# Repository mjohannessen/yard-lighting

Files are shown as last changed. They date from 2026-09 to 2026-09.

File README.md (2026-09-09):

# yard-lighting

Distributed outdoor RGB LED garden lighting system. See [CLAUDE.md](CLAUDE.md) for the full architecture, hardware, and protocol spec.

## Wiring

Fixture heads use the fiber-optic flower-stem design in
[docs/fixture_construction_fiber.md](docs/fixture_construction_fiber.md) — a
buried base enclosure with a WS2815 node (used single-line, WS2811-style)
feeding a flexible fiber-optic + spring-wire stem up to a passive frosted
globe. The fiber's polished base end seats in direct contact against the
node's flat SMD face — no reflector cone, no air gap. There is no rigid pipe
riser and no electrical connection above the base enclosure.

### System overview

```
                     ┌──────────────────────┐
                     │  Mac Mini: openHAB   │
                     │ (schedules, scenes,  │
                     │  astro/weather rules)│
                     └──────────┬───────────┘
                                │ MQTT (LAN)
                                ▼
                     ┌──────────────────────┐
                     │  Hub Box             │
                     │  Pi Zero 2 W         │
                     │  Mosquitto broker +  │
                     │  MQTT↔serial bridge  │
                     └──────────┬───────────┘
                                │ USB (Hub+Ethernet HAT → powered USB hub)
          ┌─────────────┬─────────────┬─────────────┐
          ▼             ▼             ▼             ▼
     ┌─────────┐   ┌─────────┐   ┌─────────┐   ┌─────────┐
     │ Pico #1 │   │ Pico #2 │   │ Pico #3 │   │ Pico #4 │
     │ Zone 1  │   │ Zone 2  │   │ Zone 3  │   │ Zone 4  │
     └────┬────┘   └────┬────┘   └────┬────┘   └────┬────┘
          │ GP0         │ GP0         │ GP0         │ GP0
          ▼             ▼             ▼             ▼
     ┌───────────────────────────────────────────────────┐
     │       74AHCT125 — one chip, 4 channels             │
     │   (single quad level shifter; all 4 Picos share    │
     │            it, one channel per zone)                │
     └────┬────────────┬────────────┬────────────┬────────┘
          ▼             ▼             ▼             ▼
      300–470Ω      300–470Ω      300–470Ω      300–470Ω
      resistor on   resistor on   resistor on   resistor on
      zone 1 data   zone 2 data   zone 3 data   zone 4 data
      lead, at      lead, at      lead, at      lead, at
      chip output   chip output   chip output   chip output
          │             │             │             │
          ▼             ▼             ▼             ▼
      trunk cable,  trunk cable,  trunk cable,  trunk cable,
      zone 1        zone 2        zone 3        zone 4
      (12V·GND·Data, base enclosure to base enclosure)
          │             │             │             │
          ▼             ▼             ▼             ▼
      1st fixture,  1st fixture,  1st fixture,  1st fixture,
      zone 1:       zone 2:       zone 3:       zone 4:
      +100µF cap    +100µF cap    +100µF cap    +100µF cap
      across        across        across        across
      12V/GND at    12V/GND at    12V/GND at    12V/GND at
      node's leads  node's leads  node's leads  node's leads
```

### Per-fixture base enclosure wiring

Each fixture is a buried base enclosure (no rigid pipe riser) housing a
WS2815 node (LED holder insert, direct-contact fiber coupling) and the fixed
end of the fiber/spring-wire stem. The node's leads are permanently soldered
to two short pigtails at bench-assembly time, before the enclosure is ever
closed and sealed. Each pigtail exits through its own small sealed grommet
and ends in bare tinned lead wire — no connector is fitted at bench time.
Splicing to the trunk cable happens later, at install, **outside** the
enclosure, using gel-filled direct-bury connectors — a permanent splice, not
a field disconnect. A coiled service loop of extra trunk cable at each
fixture allows a future cut/re-splice without pulling new wire.

```
  trunk in ──────────┐                       ┌────────── trunk out
  (from prev fixture,│                       │           (to next fixture,
   or hub box)        │                       │            or none if last
  12V / GND / Data    │                       │            in zone)
                       ▼                       ▼           12V / GND / Data
         gel-filled direct-bury splices (outside enclosure)
      ┌─────────┐ ┌─────────┐ ┌──────────┐ ┌──────────┐
      │   12V   │ │   GND   │ │ data-in  │ │ data-out │
      │ 3-way tie│ │ 3-way tie│ │ 2-way    │ │ 2-way    │  NOT tied together
      └────┬────┘ └────┬────┘ └────┬─────┘ └────┬─────┘
           │           │           │            │
           │  (pigtail leads — bare wire, exit through sealed grommets)
           │           │           │            │
           ▼           ▼           ▼            ▲
        ┌───────────────────────────────────────────┐
        │     Base enclosure (sealed once, on the     │
        │             bench, at build time)            │
        │        ┌───────────────────────────┐        │
        │        │  WS2815 node (LED holder   │        │
        │        │  insert, direct-contact    │        │
        │        │  fiber coupling)           │        │
        │        └─────────────┬───────────────┘        │
        └──────────────────────┼───────────────────────┘
                                ▼
                    fiber → spring wire → globe
                    (flex zone: optics + mechanics only,
                     no electrical connection above this point)
```

Notes:
- Mark fixtures with one small hole on the DIN side, 2 holes indicate the first fixture in the node which has the capacitor between + and -
- **12V and GND** are a true common tie — one gel-filled connector each,
  with trunk-in, trunk-out, and the node's own pigtail lead all landed
  together.
- **Data is never a common tie.** The node fully decodes and regenerates the
  signal, so trunk-in-data→node-DI and node-DO→trunk-out-data are two
  separate gel-filled connectors. Tying all four data leads into one
  connector shorts the node's input and output together.
- The last fixture in a zone has no trunk-out — its connectors only carry
  trunk-in + node lead (or trunk-in + node-DI, with no downstream DO
  consumer).
- Data conductors must reach the node's own pads or a gel-filled connector
  only — never spliced mid-cable underground. See §5 of the fixture
  construction guide for the full convention.

### Wire/conductor legend

| Signal | Splice rule |
|---|---|
| 12V | Common-tie gel-filled direct-bury connector, outside the base enclosure |
| GND | Common-tie gel-filled direct-bury connector, outside the base enclosure |
| Data | Two separate gel-filled connectors (in→DI, DO→out) — never a common tie, never mid-cable |

## 3D-printed parts

The globe cradle and base enclosure are designed in FreeCAD; part specs,
dimensions, and construction steps are in [freecad.md](freecad.md).
Sources (`.FCStd`) and exported print files live in [freecad/](freecad/).

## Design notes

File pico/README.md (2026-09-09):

# Pico Firmware — MicroPython Setup & Bench Test

Covers flashing MicroPython onto a Pico and running the bench-test script
(`test_bench.py`) to validate the Pico → 74AHCT125 → LED signal path before
any serial/MQTT protocol exists. See [docs/wiring.md](../docs/wiring.md) for
the bench-test-stage vs. field-deployment wiring context.

## 0. Identify the board before flashing

- Pi zero is at 192.168.1.120

CLAUDE.md specifies RP2350 Pico 2 (standard, not Pico 2 W) as the architecture
constraint, but **confirm the actual chip on each board** before flashing —
don't assume, since earlier boards bought before the fleet standardized may
still be RP2040. Put the Pico in BOOTSEL mode (see step 2) and check:

```bash
dmesg | tail -20
```

Look at the `Product:` string:
- `Pico Boot` → RP2040 → use the `RPI_PICO` firmware
- `RP2350 Boot` → RP2350 (Pico 2 generation) → use the `RPI_PICO2` firmware

Flashing the wrong family's `.uf2` doesn't brick the board, but the
bootloader silently rejects the mismatched image — the board just stays in
BOOTSEL mode with no error and no `/dev/ttyACM0` ever appears, which looks
identical to a stuck/failed flash.

## 1. Install mpremote (on the Pi)

Raspberry Pi OS Bookworm blocks bare `pip install` outside a venv (PEP 668),
so use `pipx`:

```bash
sudo apt update && sudo apt install -y pipx
pipx install mpremote
pipx ensurepath
# reopen the shell (or `source ~/.bashrc`) so mpremote is on PATH
mpremote --version
```

If `pipx` isn't available, fall back to:
```bash
sudo apt install -y python3-pip
python3 -m pip install --user --break-system-packages mpremote
```

## 2. Flash MicroPython

1. Unplug the Pico's USB cable.
2. **Press and hold BOOTSEL**, plug the cable back in while still holding
   it, wait ~2 seconds, then release. It enumerates as a USB mass-storage
   drive instead of a serial port.
3. Confirm with `lsblk` — a new small (~128MB) disk appears (e.g. `sda1`).
4. Download the firmware matching the chip identified in step 0 (check
   https://micropython.org/download/ for the current release if these exact
   URLs have moved on):
   ```bash
   # RP2040 ("Pico Boot"):
   wget https://micropython.org/resources/firmware/RPI_PICO-20260406-v1.28.0.uf2 -O ~/micropython-pico.uf2

   # RP2350 ("RP2350 Boot", Pico 2 generation):
   wget https://micropython.org/resources/firmware/RPI_PICO2-20260406-v1.28.0.uf2 -O ~/micropython-pico2.uf2
   ```
5. Mount and copy:
   ```bash
   sudo mkdir -p /mnt/pico
   sudo mount /dev/sda1 /mnt/pico   # adjust device name per lsblk
   sudo cp ~/micropython-pico2.uf2 /mnt/pico/   # or micropython-pico.uf2 for RP2040
   sync
   ```
   The Pico reboots on its own once the copy finishes and the mass-storage
   drive disappears — that's normal, not an error.
6. Confirm it's back as a serial device:
   ```bash
   ls /dev/ttyACM*
   ```

## 3. Deploy and run the bench test

```bash
cd ~/Documents/yard-lighting
git pull
mpremote connect /dev/ttyACM0 cp pico/test_bench.py :main.py
mpremote connect /dev/ttyACM0 repl
[enter]
[>>>]
CTRL-D
[enter number of leds]

```

Copying to `:main.py` makes it run on every boot/reset — but copying alone
doesn't trigger that reset, so after `repl` connects you'll just see a
blank prompt. Press **Ctrl-D** to soft-reset the board; that runs
`main.py`, which immediately prints:

```
Number of LEDs:
```

Type the count of NeoPixels currently wired on GP0 (e.g. `1` when
isolating a single fixture on the test jig) and press Enter. It then
drives a rotating rainbow across all of them — each LED position gets a
distinct hue, and the pattern shifts continuously — to confirm the signal
path end to end. With a single LED it just sweeps that one fixture through
the full color wheel.

To disconnect the REPL without resetting the board, press **Ctrl-]**. To
re-run with a different LED count, reconnect (`mpremote connect
/dev/ttyACM0 repl`) and press Ctrl-D again.

## 4. 74AHCT125 wiring (bench test / single zone)

The 74AHCT125 is a quad buffer — 4 independent channels, each with an input
(`nA`), output (`nY`), and an **active-low** output-enable (`nOE`). CLAUDE.md's
build uses a single chip, all 4 channels, one per zone (the project is capped
at 4 zones); for a single-zone bench test, channel 1 is enough.

DIP-14 SN74AHCT125N pinout, channel 1:

| Signal | Pin | Connects to |
|---|---|---|
| 1A (input) | 2 | Pico GP0 |
| 1Y (output) | 3 | → 300–470Ω resistor → LED strip DIN |
| 1OE (output enable, active-low) | 1 | Tie to GND |
| VCC | 14 | 5V rail |
| GND | 7 | Common ground (Pico GND + LED GND) |

**1OE must be tied to GND**, not left floating — floating output-enable is
undefined logic and can leave the channel not driving at all, which looks
identical to a GP0-not-connected fault (LEDs just stay dark with no error
anywhere).

For additional zones on the same chip, repeat with channel 2 (2A=pin5,
2Y=pin6, 2OE=pin4), channel 3 (3A=pin9, 3Y=pin8, 3OE=pin10), and channel 4
(4A=pin12, 4Y=pin11, 4OE=pin13) — VCC/GND (pins 14/7) are shared across all
four channels on the chip.

## Troubleshooting

- **`mpremote ... TransportError: could not enter raw repl`** — the board
  isn't running MicroPython. Either it still has different firmware from a
  previous project, or the last flash was the wrong chip family (see step
  0). Re-flash with the correct `.uf2`.
- **BOOTSEL drive never appears in `lsblk`** — BOOTSEL timing is finicky
  through a hub. Fully unplug, hold the button *before* plugging back in,
  hold for ~2s after, then release.
- **Script runs but LEDs stay dark** — check GP0 → 74AHCT125 pin 2, and
  confirm pin 1 (1OE) is tied to GND, not floating.
- **LED shows a wrong color instead of the one commanded** (e.g. solid
  white comes out green or blue, and it's a *different* wrong color on a
  different run of the same script) — check that the LED's power supply
  ground and the Pico/74AHCT125 ground are actually tied together, not
  just both eventually routed to the same fixture. Without a common
  ground the node has no shared reference for the data signal's high/low
  thresholds, so it latches whatever crosses threshold rather than the
  intended value — confirmed root cause on the bench jig, see
  [docs/fixture_test_jig.md](../docs/fixture_test_jig.md).

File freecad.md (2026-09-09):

# Globe Cradle

A 3D-printable spherical cradle mount designed to hold a 59mm diameter globe,
with a bottom nipple to accept a 1/4" ID / 3/8" OD tube (interference/pressure
fit, no adhesive — see Assembly below; confirmed with the user 2026-07-29,
superseding the glued fit this part originally shipped with).

## Part Specifications

| Feature | Dimension |
|---|---|
| Globe diameter | 59mm |
| Inner radius (cup) | 29.5mm |
| Outer radius (cup) | 32mm |
| Wall thickness | 2.5mm |
| Cradle depth | ~7.4mm (1/8 globe) |
| Nipple outer radius  | 7.36mm |
| Nipple bore radius | 4.5mm (interference fit — was 4.86mm slip-fit-for-glue) |
| Nipple length | 20mm |
| Bore depth | 15mm |
| Tube OD (press fit)  | 9.525mm (3/8") |
| Tube ID | 6.35mm (1/4") |

## Files

- `models/light-cradle-top-refined.3mf` — current printable export (FreeCAD-generated mesh); this is the file actually in the repo and the one that's been printed and fit-tested
- No `.FCStd` source is currently checked into this repo — if it lives only in a local FreeCAD session or another location, add it here so the mesh isn't the only copy

## Suppliers

- Globe: https://www.superiorlighting.com/6-inch-plastic-globe-plain-lip-opening-white-opal-acrylic/

## As-built vs. this doc (2026-09-02)

Measured directly from `models/light-cradle-top-refined.3mf`'s mesh (2051 vertices /
4102 triangles), since no `.FCStd` source is in-repo to check against:

- **Globe stays 59mm** — confirmed with the user 2026-09-02, not changing.
- **Cup/rim diameter checks out.** The spec table's "outer radius (cup) 32mm" is the
  *sphere primitive's* radius used in the boolean construction (Construction Method
  step 1), not the finished rim's opening size — those are different numbers by
  design, and the table didn't distinguish them. For a 1/8-height cap of a 59mm
  globe, the rim opening's actual radius works out to ≈19.5mm (`sqrt(R² - (R-h)²)`
  with R=29.5mm, h=7.4mm), i.e. ≈39mm diameter — and the mesh measures a 40mm
  overall diameter at that rim. These agree; no design change here, just a doc
  ambiguity worth this note so it doesn't get mis-read as a mismatch again.
- **Nipple bore does not match this doc's spec, and this one is unresolved.** The
  doc specifies a 4.5mm bore radius (9mm diameter) sized for an interference press-fit
  against the 9.525mm-OD tube (see the Nipple bore radius row and the note below the
  spec table). The mesh's nipple, however, has a ~2.8mm-diameter (r≈1.4mm) center
  bore through most of its ~19mm length — sized like the *fiber-only* hole from the
  LED holder insert in
  [docs/fixture_construction_fiber.md](docs/fixture_construction_fiber.md) §1, not a
  tube-interference bore. The nipple's outer shaft also reads ~9.6mm OD (close to the
  tube's own 9.525mm OD), with a wider collar near the cup and a small flange at the
  tip. A triangle mesh doesn't preserve feature intent, so this could be: (a) the tube
  design changed to slide over the nipple rather than press into a bore, with the fiber
  routed through a separate small channel, or (b) this file is genuinely a different
  part (closer to the LED holder insert) that inherited the "cradle" name. Since the
  user has printed and fit-confirmed the current cradles, whichever it is clearly
  works — but the written spec below (Nipple bore radius, and the interference-fit
  note) is stale relative to the actual file and should be corrected once the intent
  is confirmed against the `.FCStd` source rather than the exported mesh.

## Construction Method

Built in FreeCAD 1.1.1 using the Part workbench:

1. Outer sphere primitive (32mm radius, full sphere)
2. Inner sphere primitive (29.5mm radius, full sphere)
3. Boolean Cut: outer minus inner → hollow shell
4. Box primitive (100x100x100mm) positioned to crop upper portion
5. Boolean Cut: shell minus box → cradle cup shape
6. Cylinder primitive for nipple outer wall (7.36mm radius, 20mm height)
7. Boolean Union: cup + nipple cylinder
8. Cylinder primitive for bore (4.5mm radius, 15mm height)
9. Boolean Cut: assembly minus bore cylinder → finished part

Bore radius revised from an earlier 4.86mm (a slip fit sized for adhesive)
down to 4.5mm — roughly 0.5mm diametral interference against the 9.525mm
tube OD, confirmed with the user 2026-07-29 in favor of a pressure-only
push-fit (no epoxy/PVC cement) per the Assembly section below. This
joint doesn't need to be watertight — nothing above the base enclosure is
electrical — it only needs to hold mechanically under the globe's weight
and wind-driven stem flex. FDM prints commonly come out slightly
undersized on holes, so test-fit the bore on the PLA prototype first and
adjust the radius before committing to an ASA production run.

## 3D Printing Notes

- Recommended material: PETG or PLA
- Layer height: 0.2mm - cups use 0.12mm reduce outer wall speed to 30-40mm/s
- Infill: 40%+ for strength around nipple
- Print orientation: cup opening facing up

## Assembly

1. Assemble base/led mount
2. Connect incoming/outgoing 12v/ground/data to led leads
3. Tubing/wire retainer are the same length, fiber is 50mm longer than tubing
4. Insert tubing through lid via compression seal and insert into nipple (pressure only)
5. Thread fiber through top of globe cup
6. Thread retaining wire into tube until flush with tube.
7. Adjust fiber so it seats into the led housing hole
8. Attach globe cup to tubing (pressure only)
9. Attach globe to holder

## Disassembly

1. Open base and disconnect incoming/outgoing wires
2. Remove globe from globe cup
3. Remove globe cup from tube
4. Remove fiber/wire from tubing
5. Remove tube from led retainer
6. Remove led retainer from base

## Base Housing

Weatherproof lower enclosure that sits at (not below) grade, holding the
30mm x 30mm x 10mm LED/fiber-alignment mount and the base of the stem.
Pinned to the ground with common drip-irrigation metal loop stakes rather
than buried, since burial was moved to the trunk cable only — the housing
itself stays at the surface, exposed to sprinklers and rain but not
flooding, and must be watertight since it contains the LED.

Design decisions locked in for this part, confirmed with the user
2026-07-29:
- **One-piece, sealant-sealed shell, but sealed once on the bench, not in
  the field.** The node's 4 leads (12V, GND, DIN, DOUT) are permanently
  soldered inside the housing to two short pigtails *before* the housing is
  closed and sealed — this whole assembly happens at build time, not at
  install time. Each pigtail ends in bare tinned lead wire, not a
  connector — the connection to the trunk cable is made later, at install,
  outside the housing (see connector decision below). Superseded 2026-08-27:
  the box is no longer field-swappable as a sealed unit; "failure" now means
  cutting the splices open and re-splicing, not unplug-and-swap. See the
  trade-off note there.
- **Cylindrical puck** shape — simplest Part-workbench boolean sequence
  (concentric cylinders), no corners to catch a mower/trimmer at grade.
- **Gel-filled direct-bury splice connectors at each of the two cable
  penetrations, spliced *outside* the housing, not through a bulkhead
  cutout.** Superseded 2026-08-27 — this section originally specified
  Deutsch DT-series quick-disconnect connectors (DT04-3P plug / DT06-3S
  socket) for field-swappability without cutting/resplicing wire; that
  decision was reversed in favor of lower cost and no dedicated crimp tool,
  accepting slower field service in exchange (rare fixture failures don't
  justify the added connector/tooling cost). Each pigtail exits the housing
  through a small sealed grommet bore and ends in bare wire a short distance
  outside the shell. The buried trunk cable's in/out ends are joined to the
  pigtails there with gel-filled direct-bury connectors (ZONE INDUSTRY CORP
  silicone-filled, UL 486G — see
  [docs/fixture_construction_fiber.md](docs/fixture_construction_fiber.md)
  §2 BOM), twist-on, no tool required. A coiled service loop of extra trunk
  cable at each box allows a future cut/re-splice without pulling new wire.
  Servicing a fixture = dig down to the box, cut all splices open, lift the
  box, splice in a replacement box's pigtails using the service loop's
  slack, rebury. This still eliminates the lever-nut-inside-the-box splice
  cavity from the earliest design — the splice just moved outside the box
  and changed connector technology twice since — see
  [docs/fixture_construction_fiber.md](docs/fixture_construction_fiber.md)
  §5 for the full wiring convention and BOM.
- **Stem port keeps the mount's stem boss fully inside the housing.** The
  mount's stem-side boss is 15mm dia x 10mm tall; the silicone tube itself
  is 9.525mm OD. Rather than letting the 15mm boss poke through the housing
  top (which would need an ~16mm port and leave the boss exposed to
  weather), the housing top port is sized to the **tube**, just above where
  it seats on the boss. This keeps the boss-to-tube joint fully enclosed and
  protected, and only the plain tube crosses the watertight boundary. If
  bench-fit shows the tube needs to seat *above* the housing top instead
  (e.g. the boss has to sit proud for stem geometry reasons), widen the
  port and revisit — flagged here so the trade-off isn't silently
  re-decided later.
- **Stem port seals with a compression grommet, not a sealant bead directly
  on the tube.** Confirmed with the user 2026-07-29: cured silicone sealant
  doesn't reliably bond to the tube's own cured-silicone surface (both are
  chemically the same inert, low-surface-energy material, so a sealant bead
  applied there mostly sits on top rather than adhering — a real risk at a
  joint that flexes every time the stem moves in the wind). Instead, the
  port holds a small rubber compression grommet (same category part as the
  IP68 cable glands used elsewhere in this project) sized to the tube's
  9.525mm OD, sealing by mechanical squeeze rather than adhesion. Sealant
  is still used, but only as a secondary bead around the grommet's own
  flange-to-cap joint — rigid printed plastic to rigid grommet body, which
  sealant bonds to fine, unlike the tube itself.

### Part Specifications

| Feature | Dimension | Notes |
|---|---|---|
| Overall shape | Cylindrical puck | Sits flush at grade |
| Outer diameter | 70mm | Shrunk from an earlier lever-nut-based draft (95mm) now that the node wires straight to pigtails with no in-box splice hardware — encloses the 30x30mm mount + pigtail dressing with margin |
| Overall height | 40mm | 30mm cup + 10mm cap, before final trim |
| Wall thickness | 3mm | Thicker than the globe cradle's 2.5mm — this part carries stake-down load at the flanges |
| Mount cavity (on internal boss)| 34mm x 34mm x 12mm | 2mm clearance around the 30x30x10mm mount block on each side and above |
| Stem port (in cap) | ~4mm tall collar, counterbored for a compression grommet | Grommet ID matches 9.525mm tube OD, seals by mechanical squeeze; grommet OD/flange size is [TBD] — confirm against the actual grommet product before finalizing the counterbore |
| Pigtail exit bores (in floor)  | 2x ~8mm bore, small grommet/potted seal | Trunk-in-side, trunk-out-side pigtail; offset to the side of the mount boss. Not a full trunk-cable gland — the actual splice (gel-filled direct-bury connector) sits outside the housing |
| Stake-mount flanges | 2x, opposite sides, 18mm x 12mm, 4.5mm through-hole | Sized for typical drip-irrigation loop-stake wire (~3mm dia) |
| Cap-to-cup joint | 2mm deep overlapping lip | Sealant-bead seam, sealed once at bench-assembly time |

### suppliers
- underground wire: https://cheapsprinklers.com/products/18-3x250-wire-18-3-x-250ft

### Construction Method

Built in FreeCAD 1.1.1 using the Part workbench — two separate solids (cup
and cap), same boolean-first approach as the globe cradle:

**Cup (lower body):**
1. Outer cylinder, 35mm radius, 30mm height
2. Inner cylinder cut, 32mm radius, positioned to leave a 3mm floor →
   hollow cup
3. Box or cylinder **union** for the internal mount boss (raised platform
   inside the cup floor, ~5mm tall, footprint sized to the 34mm x 34mm
   mount cavity) — a boss, not a recess, so the LED sits above any water
   that reaches the true floor
4. Two cylinder cuts through the floor for the pigtail exit bores (~8mm),
   offset to the side of the mount boss
5. Two box **unions** for the stake-mount flanges at the outer rim (opposite
   sides), then two cylinder cuts through each flange for the stake
   through-holes

**Cap (lid):**
6. Outer cylinder matching the cup's outer lip diameter, ~10mm height
7. Inner cylinder cut sized to the cup's 2mm overlap lip → thin disc that
   seats over the cup
8. Cylinder **union** for the stem-port collar (~4mm tall boss centered over
   where the mount's stem boss will sit)
9. Cylinder cut through the collar for the stem port, sized to the chosen
   grommet's insertion OD
10. Shallow counterbore cut at the collar's top face, sized to the
    grommet's flange OD and thickness, so the grommet seats flush and can't
    push through under stem movement

### 3D Printing Notes

- Prototype in PLA on the Anycubic Kobra to fit-check the mount cavity,
  pigtail exit bores, and stake-flange spacing before committing to ASA,
  per the existing fixture fabrication workflow's two-material process
- Recommended production material: ASA (UV/thermal stability for a
  surface-sited, full-sun part) — not PLA, per established workflow
- Layer height: 0.2mm; reduce outer wall speed near the stem-port collar
  and stake-flange holes for cleaner small-feature detail
- Infill: 40%+, especially through the stake-flange bosses — these carry
  the pinning load from the ground stakes
- Print orientation: cup opening facing up; cap printed flat, port collar
  facing up

### Bench Assembly (done once per box, before install)

1. Fit-check the mount block and stem boss dry in the cup's mount boss and
   cap's stem port before any sealant goes on
2. Solder the node's 4 leads to two short pigtails (in-side: 12V, GND, DIN;
   out-side: 12V, GND, DOUT), heat-shrink each joint, tin the free end of
   each pigtail wire — these stay bare leads until spliced to the trunk
   cable at install, not terminated in a connector at bench time
3. Feed each pigtail through its floor exit bore, seat the mount block on
   the internal boss, feed the stem up through the cap's port and seat the
   compression grommet in its counterbore around the tube
4. Run a continuous bead of clear flexible outdoor sealant (GE Silicone II,
   Sikaflex, Loctite Marine — not epoxy, matching the globe-seam convention)
   around the cup-to-cap lip, the grommet's flange-to-cap joint, and each
   pigtail exit bore — the grommet itself, not sealant, is what seals
   against the tube
5. Seat the cap onto the cup, tool the sealant fillets so water sheets off
   each joint rather than pooling; let cure per datasheet
6. Bench-test the node before it ever goes in the ground

### Field Install / Service

1. Strip the buried trunk cable's in/out ends and splice each to the
   corresponding pigtail leads with gel-filled direct-bury connectors
   (ZONE INDUSTRY CORP, per BOM), outside the housing
2. Coil a service loop of extra trunk cable near the box before
   backfilling, so a future re-splice doesn't require pulling new wire
3. Pin the housing to grade with a loop stake through each of the two
   flange holes, prongs pushed fully into soil
4. Confirm level and flush-to-grade seating, then backfill up to (not over)
   the housing
5. **To service a failed fixture**: dig down to the box, cut all splices
   open, lift the box out, splice in a replacement box's pigtails using the
   service loop's slack, rebury

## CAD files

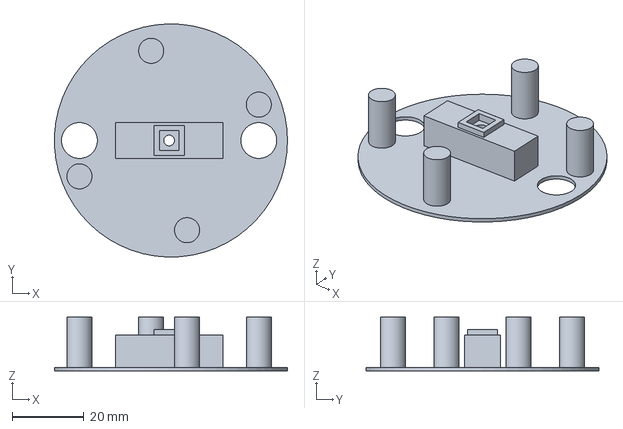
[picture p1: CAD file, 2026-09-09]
freecad/led-insert.FCStd
65.0 x 65.0 x 15.0 mm

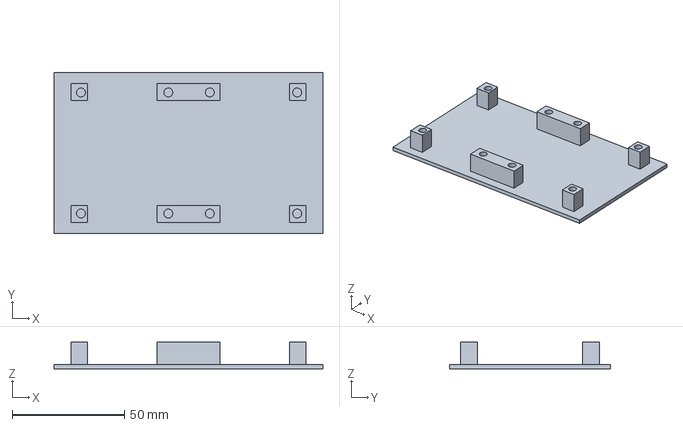
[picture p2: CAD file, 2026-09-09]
freecad/outdoor led final models/box-part-mounts-buck-plate.3mf
120.0 x 72.0 x 12.0 mm

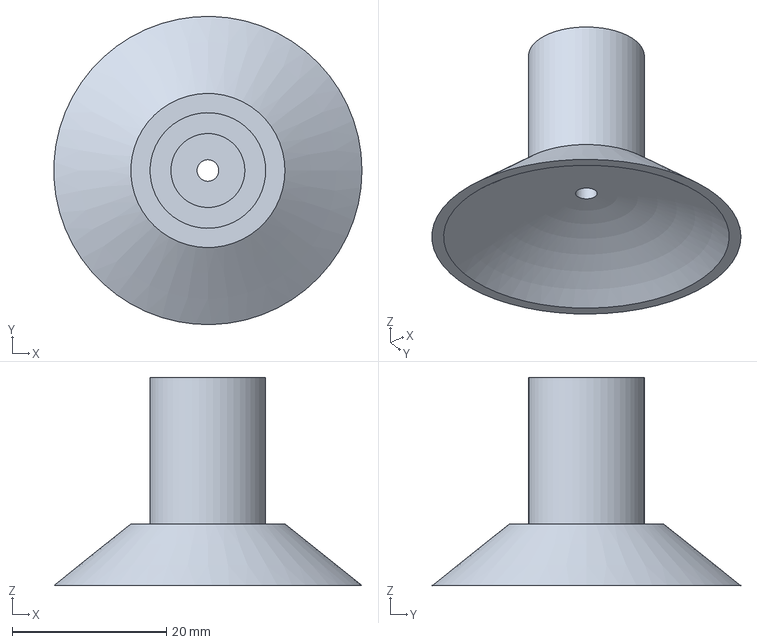
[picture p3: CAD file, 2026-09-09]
freecad/light-cradle.FCStd
40.0 x 40.0 x 27.0 mm

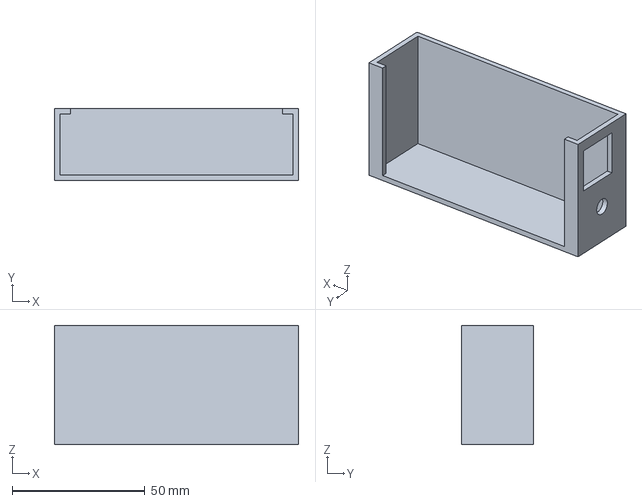
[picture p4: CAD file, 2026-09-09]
freecad/outdoor led final models/usbholder.3mf
92.0 x 27.0 x 45.0 mm

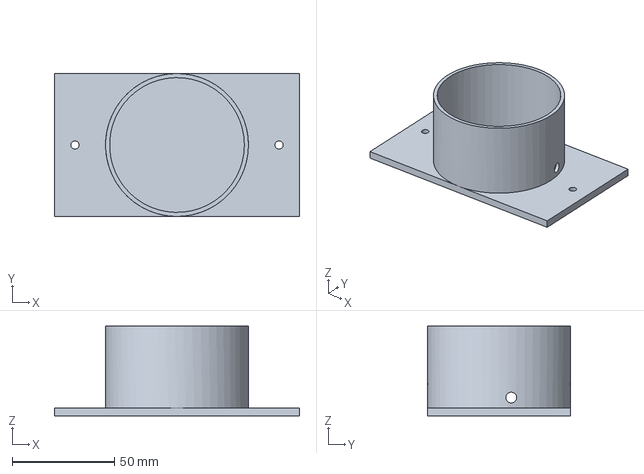
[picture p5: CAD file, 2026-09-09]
freecad/light-fixture-housing-base.FCStd
120.0 x 70.0 x 44.0 mm

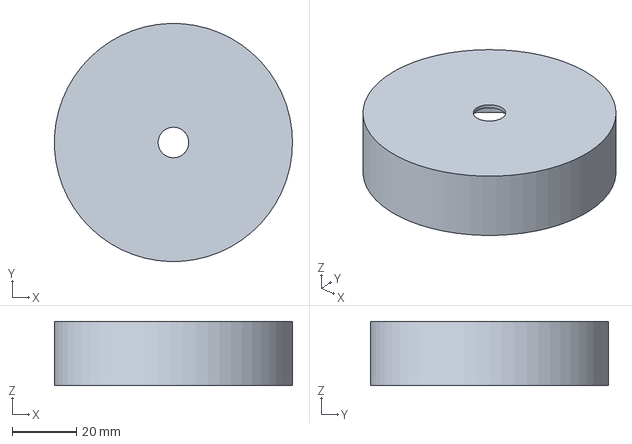
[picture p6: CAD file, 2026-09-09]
freecad/light-fixture-housing-cap.FCStd
73.9 x 74.0 x 20.0 mm

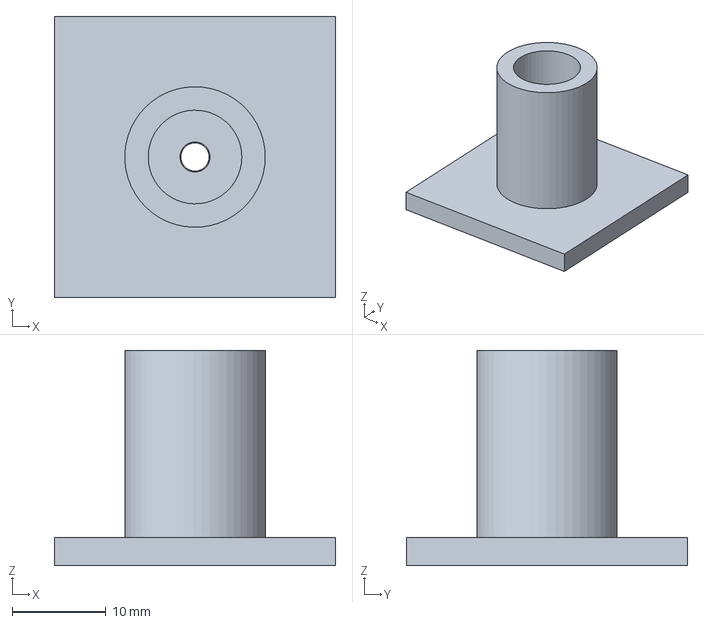
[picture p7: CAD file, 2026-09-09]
freecad/led-interior-mount-top.FCStd
30.0 x 30.0 x 23.0 mm

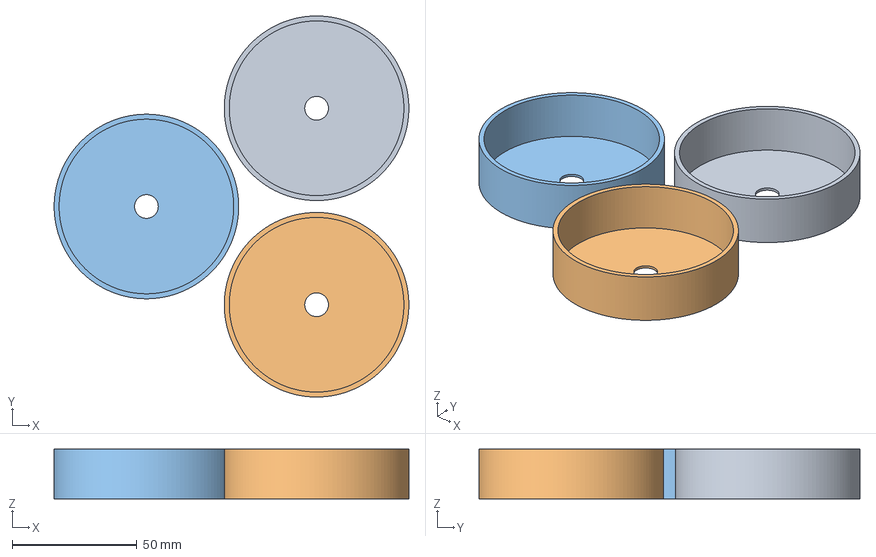
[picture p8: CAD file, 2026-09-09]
freecad/outdoor led final models/light-fixture-housing-cap.3mf
142.2 x 152.8 x 20.0 mm

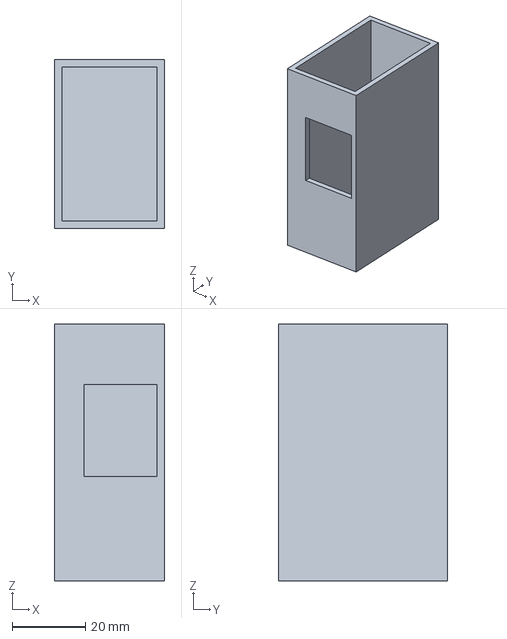
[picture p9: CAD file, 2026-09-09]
freecad/outdoor led final models/piholder.3mf
30.0 x 46.0 x 70.0 mm

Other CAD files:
freecad/outdoor led final models/led-insert.3mf
freecad/outdoor led final models/light-cradle-top-refined.3mf
freecad/outdoor led final models/led-interior-mount-top-Cut003.3mf
freecad/box-part-mounts.FCStd
freecad/outdoor led final models/light-fixture-housing-base.3mf

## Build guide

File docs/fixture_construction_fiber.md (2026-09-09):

# Fixture Construction Guide — Fiber-Optic Flower-Stem LED

1.  3d print parts:
    - base and cap = PETG
    - globe cup, led retainer and upper nipple all PLA
2.  Cut silicon tube to desired length
3.  Cut retaining wire (coat hanger wire) to the length of the silicon tube
4.  Cut the fiber 60mm longer than the silicon tube
5.  Cut diffuser rod to 10mm lengths
6.  Drill fiber hole in diffuser 1/2 of length
7.  Polish the fiber end touching the led — this end must stay clear and flat,
    the opposite treatment from the frosted globe-end tip in Step 6:
  - Score and snap, or cut square with a sharp blade/fiber-optic cutting tool,
   as close to perpendicular to the fiber axis as you can get by eye.
  - Wet-sand the end face flat against fine sandpaper on a hard, flat surface
   (a scrap of glass or tile works), fiber held perpendicular to the paper.
   Step through grits: ~400 → 600 → 1000 → 1500 → 2000, a few figure-eight
   strokes per grit, wiping the face clean between grits so a coarser
   scratch doesn't carry forward.
  - Finish with a metal-polish compound (e.g. Brasso) on a soft cloth or
   felt pad, or a plastic-polish compound (e.g. Novus 2/1), until the face
   looks clear rather than frosted — held up to light, you should see
   through it, not a matte scatter.
  - Inspect the finished face against a light source: it should be flat,
   perpendicular, and glassy-clear with no visible scratches, chips, or
   rounding at the edge before seating it against the LED.
8. Glue diffuser to unpolished end of fiber

# Final Assembly
1.  Cut 2 pigtails from the main cable 20cm each, Strip one end 70mm (inside), the other 30mm and strip ends
2.  Feed lond end of supply pigtail through the fixture and bend upwards
3.  Pull led wires and cable wires through the retainer holes
4.  Solder connections (VCC to led, in/out red, GND to led gnd-in-out-white, blue to DIN, DOUT to continued blue)
5.  For first fixture in node, add capacitor to VCC/GND (long wire is +)
6.  Trim cap and based for tight fit
7.  Check nipples for easy tube insertion.
8.  Add globe cap to tube, insert retaining wire and fiber.
9.  insert tube into base with about 10mm inside
10. Align fiber with led hole
11. Lower cap assembly into base
12. Attach globe

- Once assembled correctly seal all joints with silicon sealant

## Stem/globe sub-assembly (moved from docs/fixture_test_jig.md)

1.  Mark DIN on the fixture
2.  Insert the hose into the base cap and pull 1/2 way up hose
3.  Insert fiber into globe cap [glue here? - globe, cap and fiber all in place?]
4.  Insert hose into globe assembly
5.  Insert retaining wire into hose
6.  Push fiber into led holder until set
7.  Seat hose into base nipple
8.  Pull down cap to seat - adjust hose for fit
9.  Add globe to top (see 3)

## Component measurements

**Note:** these predate, and have not been reconciled with, the nipple
bore discrepancy already flagged in freecad.md (spec vs. as-printed mesh) —
treat both as unresolved until checked against current printed parts.

base nipple
  - total depth 35mm - 25mm for hose - additional 10mm for fiber to led hole
globe assembly
  - hose insert depth 10mm
  - from nipple entrance to top of diffuser - 60mm
    - hose insert - 10mm
    - fiber + diffuser - 50mm
    - inside cradle to diffuser top - 35

Example - for fiber 240mm
  - hose/wire 180

# Bill of materials

WS2815, 5050 SMD, DC12V, individually addressable | Cut singly from a [12V WS2815 strip, 60 LEDs/m](https://www.superlightingled.com/12v-ws2815-individually-addressable-5050-rgb-led-lights-strip-60ledsm-p-2133.html); 
Fiber optic cable -  PMMA (acrylic) end-glow fiber, ~3mm core 
Spring wire | 304 stainless steel, straight, full-hard temper, 1.4/1.6/1.8mm (bench-test set) or coathanger wire
Silicone tubing | Black silicone, 1/4"ID x 3/8"OD 
Diffuser bead  ~10–15mm frosted/opal acrylic bead  Epoxied to the fiber's globe-end tip 
Fine grit sandpaper
2.5" frosted acrylic ball
100% silicone sealant — GE Silicone II (or equivalent)
18 AWG 3 conductor underground wire

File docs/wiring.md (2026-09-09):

# Wiring — Bench Test Stage → Field Deployment

## Stage 1: Bench test (current)

Goal: validate the Pico → dispatch → LED signal path for two independent
zone branches before adding the field-scale power system (buck converters,
underground runs, WS2815 strings).

**Setup:** 2 Picos (one per branch), 24V bench PSU feeding both a 24V→5V
buck (Picos) and a 24V→12V buck (LED power), 1 real WS2815 node per Pico.
Each Pico's node will later gain a second WS2815 on the same branch (2
nodes per Pico) — not yet wired.

**Pins (same as field deployment, per Pico):**
| Pin | Function |
|---|---|
| GP0 | Data out → 74AHCT125 input |
| VBUS | 5V in |
| GND | Common ground |

**Still required at bench scale:**
- **24V→5V and 24V→12V buck converters** — both now in the loop, off the
  same 24V bench PSU, same as field deployment. No more standalone 5V
  supply standing in for them.
- **74AHCT125 level shifter**, one gate per Pico's GP0/data line (2 of the
  chip's 4 gates used; both Picos share the same physical chip). This isn't
  a 12V-vs-5V power concern — it's that the Pico's 3.3V logic sits below the
  ~5V (0.7×Vdd) data threshold NeoPixel-protocol pixels expect. A short
  bench wire may *appear* to work without it, but that's out of spec and
  won't validate the real signal path used in the field build.

**Not needed at this stage:**
- 300–470Ω data-line resistor / 100µF cap — cheap insurance if on hand;
  with only 1 WS2815 node per branch, inrush current on power-up is minimal
  (the cap's role in CLAUDE.md's *Known Constraints* is protecting the
  first node in a full field string, not a lone bench node), so not
  required yet.

**WS2815 BI/BO:** now real WS2815 nodes, so the backup-data pins physically
exist — leave them unwired at the bench too, matching the field convention
in CLAUDE.md (single-line, WS2811-style; BI/BO unused).

**Power draw:** trivial at 2 WS2815 nodes total even at full white
(~18mA/LED) — no special power sequencing needed on bench supply. Revisit
once each branch grows to 2 nodes.

## Stage 2: Field deployment (Phase 1 — 4 zones)

Real installation, replacing the bench's single 5V supply with the full 24V
power system and scaling from 2 bench branches to the 4 physical zones
leaving the hub box. One 24V/300W PSU feeds two independent buck converters
— nothing downstream shares a raw 24V rail.

```
24V/300W PSU
  │
  ├─► 24V→12V buck (5A) ──► common 12V/GND bus ──► 4× IP67/68 3-pin connector
  │                                                  └─► zone N trunk (12V + GND)
  │
  └─► 24V→5V buck (5A) ──► Pi Zero 2 W + USB Hub/Ethernet HAT
                              │
                              └─► powered USB hub ──► 4× Pico (VBUS 5V, GND, USB serial)
                                                         │
                                                         └─► GP0 ──► 74AHCT125 gate ──► 300–470Ω resistor ──► zone N trunk (Data)
```

**Power:**
- **24V→12V buck, 5A** — all 4 WS2815 strings share this converter's output
  at a common bus in the hub box; each zone taps it through its own IP67/68
  connector, not a shared underground run.
- **24V→5V buck, 5A** — feeds the Pi Zero 2 W (via the stacked USB Hub +
  Ethernet HAT, GPIO 5V) and, through that hub's USB-A port, the powered USB
  hub. Picos draw 5V over VBUS from the powered USB hub's ports — they are
  not wired to the buck converter directly.

**Signal — one 74AHCT125, 4 zones:**
- All 4 gates of a single quad 74AHCT125 are used, one per Pico: Pico GP0 →
  gate in, gate out → that zone's 300–470Ω resistor → underground data
  conductor. The four gates are electrically independent — no bussing
  between zones, same as the separate 12V/GND taps above.
- This is the full build: the project is capped at 4 zones permanently
  (hub box space constraints), so this single chip and the 4-port USB hub
  cover the whole system — no second 74AHCT125 or expansion is planned.

**USB (Pi ↔ Picos):**
- Pi Zero 2 W → USB Hub + Ethernet HAT (stacks on GPIO header, taps Pi's USB
  via pogo pins) → one USB-A port feeds the powered USB hub → 4 Picos.
- Each Pico enumerates as `/dev/ttyACMn` in connection order; assign stable
  `/dev/ttyPICOn` symlinks via udev (see CLAUDE.md *Deployment* section)
  before wiring `pi/config.py`'s zone→port map.

**Underground trunk, ×4 (one per zone):**
- 3-conductor: 12V, GND, Data. WS2815's BI/BO backup pair is intentionally
  left unwired (see CLAUDE.md *Architecture Constraints*).
- 100µF cap across 12V/GND at each zone's first base enclosure node leads —
  not optional, protects against power-on surge.
- Splices only at base enclosure gel-filled direct-bury connectors
  (ZONE INDUSTRY CORP silicone-filled, UL 486G, 20–8 AWG — see BOM), per
  CLAUDE.md §*Underground trunk cable*; no
  mid-cable splices. Each fixture gets a coiled service loop of extra
  trunk cable to allow a future cut/re-splice, since this is a permanent
  joint rather than a field disconnect.

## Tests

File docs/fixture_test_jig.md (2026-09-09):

# Fixture Test Jig — Pre-Burial Bench Test

A standalone test rig for lighting up one fixture's WS2815 node — via its
bare pigtail leads — before the base enclosure is glued shut and before the
pigtails get spliced to trunk cable. This is what satisfies the "Node
addresses and lights correctly on the bench" line in
[docs/fixture_construction_fiber.md](fixture_construction_fiber.md) §6's
pre-burial QC checklist, done right after Step 3 (pigtails soldered) or
Step 4 (base assembled) — whichever point the enclosure is still open enough
to reach the leads — and again at Step 9 after the globe is mounted.

This is a separate, permanent bench fixture, not a one-off wiring — build it
once and reuse it for every fixture.

## Components

| Part | Notes |
|---|---|
| Pico 2 (RP2350) | Same board as the field build (CLAUDE.md architecture constraint) — running MicroPython, per [pico/README.md](../pico/README.md) |
| 74AHCT125 quad level shifter | Only 1 of 4 channels used; same part as the field build and the bench-test rig ([pico/README.md](../pico/README.md) §4) |
| 300–470Ω resistor | Data line, between the 74AHCT125's output and the node's DI clip lead — matches the field convention (CLAUDE.md *Per zone* table) |
| 100µF capacitor | Across the 12V/GND clip leads, as close to the node as the clips allow — cheap insurance against power-on surge into a single node, same reasoning as CLAUDE.md's *Known Constraints* note (protects the node on connection, when clip contact bounce can spike current briefly) |
| 3× test clip leads (or fine hook probes) | 12V, GND, DI — clip directly to the fixture's bare pigtail leads. Use the **in-pigtail** (DI), never the out-pigtail (DO) — DO is the node's regenerated output toward the next fixture in the chain and carries no signal when nothing is driving it |
| Bench power supply, 12V | Fixture LED power only — set the voltage before connecting, don't rely on the jig to protect against an unset/wrong supply voltage |
| Raspberry Pi (test host) + USB cable | Host for flashing/running the Pico over `mpremote` (see Firmware below); also powers the Pico (VBUS) and, from the Pico's VBUS pin, the 74AHCT125's 5V VCC |
| Alligator clip → bare wire, or a small terminal block | At each of the 3 test leads' fixture end, sized for the pigtails' 26–30AWG silicone lead wire ([fixture_construction_fiber.md](fixture_construction_fiber.md) §2 BOM) |

Everything above except the clip leads and bench PSU is identical to the
existing bench-test 74AHCT125 setup in
[pico/README.md](../pico/README.md) §4 — build this jig on the same
protoboard/breadboard layout if one is already on hand from that setup.

## Wiring

```
Pico VBUS (pin 40)  ──► 5V rail
Pico GND  (pin 23)  ──► 5V rail GND / 74AHCT125 pin 1 (1OE) / pin 7 (GND)
Pico GP0  (pin 1)   ──► 74AHCT125 pin 2 (1A)
74AHCT125 pin 3 (1Y) ──► 300–470Ω resistor ──► DI clip lead
74AHCT125 pin 14 (VCC) ──► 5V rail

Bench 12V PSU (+) ──► 12V clip lead
Bench 12V PSU (–) ──► GND clip lead (common with Pico/74AHCT125 GND)
100µF cap ── across the 12V and GND clip leads, at the clip end
```

(74AHCT125 indentation notch is on the lower left; see
[pico/README.md](../pico/README.md) §4 for the full pinout table.)

Clip order onto the fixture's pigtail: **GND first, then 12V, then DI** —
same reasoning as any live power connection, minimizes the chance of the
data or 12V lead briefly floating against the wrong contact while clipping
on. Unclip in reverse order (DI, then 12V, then GND).

**The three grounds must be common**: bench PSU return, Pico GND, and
74AHCT125 GND all have to tie together, exactly like the field build's
single common ground (CLAUDE.md *Pico pin assignments*). If the bench PSU
and the USB power source are two separate physical supplies (likely, since
one is 12V and the other is 5V-over-USB), run a wire between their two
negative/ground points — don't assume they share a ground just because both
eventually reach the same fixture.

**Confirmed failure mode:** a missing/floating common ground here doesn't
just leave the node dark — it produces a *wrong but plausible-looking*
color (e.g. commanding solid white and getting solid green or blue
instead, differently on different runs of the same script), because the
node has no shared zero-volt reference to judge the incoming signal's
high/low thresholds against. Check continuity between the bench PSU's
negative terminal and the Pico's GND pin (should read ~0V) before
suspecting the resistor, cap, clips, or the node itself.

**1OE must be tied to GND**, not left floating — see
[pico/README.md](../pico/README.md) §4 for why a floating output-enable
looks identical to a disconnected data line (LEDs just stay dark).

## Firmware

With the Pico connected via USB to the Pi test host, flash
[pico/test_bench.py](../pico/test_bench.py) using `mpremote` from the Pi
per [pico/README.md](../pico/README.md) §§1–3, then follow that guide's
REPL steps and enter `1` at the **Number of LEDs** prompt when testing one
fixture on this jig (it also accepts the full daisy-chained count when
testing a multi-fixture run). It then drives a rotating rainbow across all
configured LEDs — each position gets a distinct, continuously shifting hue
— which is what §6's QC checklist checks color uniformity and hot-spot
issues against.

## Using the jig

1. Set the bench PSU to 12V, **outputs off**, before clipping on.
2. Clip GND, then 12V, then DI onto the fixture's in-pigtail bare leads
   (never the out-pigtail/DO).
3. Enable the bench PSU output.
4. From the Pi test host, confirm the Pico is running `test_bench.py` and
   showing the rainbow (see [pico/README.md](../pico/README.md) §3 for
   the `mpremote`/REPL steps).
5. At the globe, check per
   [fixture_construction_fiber.md](fixture_construction_fiber.md) §6: color
   uniformity through the rainbow, no hot-spot opposite the fiber tip,
   adequate brightness, and — if the stem is already built — that hand-flexing
   the stem doesn't disturb the light (a loose LED-to-fiber contact would
   show up as flicker here).
6. Disable the bench PSU output, then unclip DI, 12V, GND in that order.

If the node doesn't light: check the DI clip is actually on the
**in**-pigtail and not the out-pigtail (both leads look identical once bare
and tinned — mark them at Step 3 of
[fixture_construction_fiber.md](fixture_construction_fiber.md) if this is a
recurring mix-up), then work through
[pico/README.md](../pico/README.md)'s troubleshooting section — the failure
modes (floating 1OE, wrong GP0 wiring) are the same on this jig as on the
bench-test rig.

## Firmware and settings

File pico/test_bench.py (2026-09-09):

"""
Bench-test-stage hardware smoke test — see docs/wiring.md Stage 1.

Confirms the physical signal path (Pico GP0 -> 74AHCT125 -> NUM_LEDS x NeoPixel)
before any serial/MQTT protocol exists. Not part of the pico/main.py
dispatch loop.

Displays a rotating rainbow across all LEDs: each position gets a distinct
hue, and the whole pattern shifts over time. With NUM_LEDS=1 this sweeps
that single fixture through the full color wheel. Useful for confirming
per-position data integrity (each fixture should show a different, stable
color, not a corrupted one) and for exercising repeated np.write() calls
at a steady pace, unlike a single static write.

Prompts for the number of LEDs over the serial REPL on each run, so the
jig can be repointed at 1 node or the full daisy-chained count without
editing this file. Requires an attached REPL session (e.g. `mpremote
connect /dev/ttyACM0 repl`, press Ctrl-D to run) to answer the prompt.
"""
from machine import Pin
from neopixel import NeoPixel
import time

DATA_PIN = 0


def wheel(pos):
    """(r, g, b) for a position 0-255 on the color wheel."""
    pos = pos % 256
    if pos < 85:
        return (255 - pos * 3, pos * 3, 0)
    if pos < 170:
        pos -= 85
        return (0, 255 - pos * 3, pos * 3)
    pos -= 170
    return (pos * 3, 0, 255 - pos * 3)


while True:
    try:
        NUM_LEDS = int(input("Number of LEDs: "))
        if NUM_LEDS > 0:
            break
    except ValueError:
        pass
    print("Enter a positive integer.")

np = NeoPixel(Pin(DATA_PIN), NUM_LEDS)

offset = 0
while True:
    for i in range(NUM_LEDS):
        np[i] = wheel((i * 256 // NUM_LEDS) + offset)
    np.write()
    offset = (offset + 1) % 256
    time.sleep(0.05)

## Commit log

2026-07-20 Update hub box hardware to Ethernet HAT, add wiring and fixture construction docs
    CLAUDE.md/README: correct hub box networking from USB-OTG hub + USB-ethernet
    adapter to the Pi Zero USB Hub + Ethernet HAT actually in use. Rewrite
    README's wiring section to match the current fiber-optic flower-stem fixture
    design (WS2811 base enclosure, 3-conductor trunk, lever-nut splicing) instead
    of the retired rigid pipe-riser/WS2815-DOUT design.
    docs/wiring.md: bench-test-stage vs field-deployment wiring reference.
    docs/fixture_construction_fiber.md: full build guide for the fixture head.
2026-07-20 Update CLAUDE.md architecture spec to match fiber-stem fixture design
    Replace stale WS2815/4-wire/PCB-pin references with the WS2811 3-conductor
    trunk + base-enclosure lever-nut design already documented in
    docs/fixture_construction_fiber.md. Covers project purpose, architecture
    constraints, hardware BOM, underground cable spec, file map, and known
    watch-outs.
2026-07-20 Add Pico bench-test firmware and MicroPython setup guide
    test_bench.py validates the Pico GP0 -> 74AHCT125 -> 2x NeoPixel signal
    path with a standalone color-cycle script, ahead of the full serial/MQTT
    dispatch loop. README.md documents flashing MicroPython (including the
    RP2040-vs-RP2350 board ID gotcha hit on the first bench Pico, which turned
    out to be RP2350-based) and the 74AHCT125 level-shifter pinout.
2026-08-27 Fix Pico chip reference and note bench Pi Zero IP
    CLAUDE.md's architecture spec already moved to RP2350 Pico 2; pico/README.md
    still said RP2040. Also note the bench-test Pi Zero's IP for reference.
2026-08-27 Switch base enclosure splicing from Deutsch connectors to gel-filled direct-bury connectors
    Field-swappable Deutsch DT connectors are overkill for this project: fixture
    failures are expected to be rare, and a coiled service loop of extra trunk
    cable at each fixture makes a future cut/re-splice cheap enough not to need
    a quick-disconnect. Switches to gel-filled direct-bury splice connectors
    (ZONE INDUSTRY CORP, UL 486G) instead, dropping both the connector cost and
    the dedicated Deutsch crimp tool. Updates CLAUDE.md, docs/wiring.md,
    docs/fixture_construction_fiber.md, and freecad.md's Base Housing section to
    describe the same convention consistently.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
2026-08-27 Bring README wiring section up to date with current fixture design
    README still described the earliest design: WS2811 node, reflector cone,
    and lever nuts spliced inside the enclosure. Updates it to match the
    current WS2815 direct-contact-fiber build and the gel-filled direct-bury
    splice convention (outside the enclosure, via pigtails) documented in
    CLAUDE.md and docs/fixture_construction_fiber.md §5.
2026-09-09 Add FreeCAD sources, fix bench-test LED count bug, rework test jig docs
    - Add freecad/ (FCStd sources, FCBak backups, exported .3mf prints) to
    version control per CLAUDE.md's documented repo layout — previously
    untracked.
    - Fix pico/test_bench.py: NUM_LEDS was hardcoded from an earlier bench
    stage and silently dropped frames for nodes beyond that count; now
    prompts for the LED count over the REPL each run instead.
    - Rewrite docs/fixture_test_jig.md to focus solely on the jig hardware
    and the Pi-hosted mpremote flash/test workflow; move fixture-assembly
    content that didn't belong there into fixture_construction_fiber.md.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
    [box-part-mounts-buck-plate.3mf, box-part-mounts.FCStd, led-insert.3mf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]
2026-09-09 Replace bench-test color cycle with a rotating rainbow
    Each LED position now gets a distinct, continuously shifting hue instead
    of the fixed red/green/blue/white/off sequence, so per-position data
    integrity is visible at a glance across however many fixtures are
    configured (still entered via the REPL prompt). Also restores continuous
    np.write() calls, unlike the earlier single-shot diagnostic variant, so
    timing-related flicker isn't masked. Updated pico/README.md and
    docs/fixture_test_jig.md to match.
    [test_bench.py]
2026-09-09 Document missing-common-ground failure mode found on the test jig
    A floating ground between the bench 12V supply and the Pico/74AHCT125
    produced wrong (not just dark) colors on the fixture, differently on
    different runs of the same command -- confirmed root cause after chasing
    what looked like a flicker/signal-integrity issue. Recorded in both
    pico/README.md's troubleshooting section and the jig doc so it's checked
    before the resistor/cap/clips/node.
2026-09-17 Add pico/pi field firmware and bridge; fix WS2815 red/green channel swap
    Adds the real JSON serial protocol firmware (main.py/effects.py/ws2811.py)
    and the pi/bridge.py MQTT<->serial bridge, replacing the bench-test
    placeholders. First end-to-end test (zone 1 scaled to 5 fixtures, all 4
    zones) surfaced two bugs: zones 2-4 had never been deployed with this
    firmware, and ws2811.py had a red/green channel swap since these WS2815
    fixtures expect RGB wire order rather than MicroPython's GRB default.
    Both fixed and reverified with a full color test.
2026-09-25 Add bridge keepalive, Pico status heartbeat, and systemd unit
    The Pico's 15s contact watchdog replaced every MQTT command with the
    amber fail-safe pulse, since nothing re-sent commands between openHAB
    updates. The bridge now re-sends each zone's last command every 5s; the
    Pico ignores identical repeats so cycle/chase animations don't restart.
    The Pico now prints a JSON status line per command, which the bridge
    publishes to garden/lights/zone/{n}/status as a 5s heartbeat.
    Zone links now outlive the MQTT connection, so zones hold state through
    a broker restart and reconnects no longer spawn duplicate serial tasks.
    Adds pi/garden-lights-bridge.service. Deployed and verified on all four
    zones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
2026-10-10 Fiber polishing jig, light cradle variants, box mounts update; docs
    Add .gitignore for .DS_Store and FreeCAD .FCBak backups.
2026-10-10 Fixtures sit on the ground, not buried; water protection and per-zone fuses
2026-10-13 README: clear globes show the LED by day, white ones don't
2026-10-13 100 ohm data resistors for the long trunk runs; bridge connects zones independently
    The 300-470 ohm series resistor plus the ~10 m trunk to a zone's first
    fixture smeared the data edges, so fixtures read random colours.
    Diagnosed 2026-10-13: a wire link and 100 ohm both run clean (solid red
    and cycle), 470 ohm garbles. Bench/jig docs keep 300-470 ohm with a note.
    bridge.py: main() awaited each zone's serial connect in turn, so one
    unplugged Pico blocked every later zone. Each zone's status_loop already
    connects its own port, so main() now just starts the keepalives.
2026-10-13 10 fixtures per zone; broker listens on the LAN for openHAB
    NUM_LEDS 10 in pico/main.py (deployed to all four Picos). pi/mosquitto-lan.conf
    is the /etc/mosquitto/conf.d/lan.conf now installed on the Pi: Mosquitto 2.x
    is localhost-only without a listener, so openHAB couldn't connect. Docs point
    to the openHAB and hauss-backend pieces.
2026-10-14 Fireflies: 0.5 s blink about every 5 s (was 10 s), jitter ±1 s
